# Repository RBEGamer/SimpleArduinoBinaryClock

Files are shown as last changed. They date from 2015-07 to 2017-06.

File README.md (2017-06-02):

# SimpleArduinoBinaryClock
Arduino based binary clock with hours and minutes display, nightmode and alarm.
It uses a Arsuino Nano and the WS2812 Leds,to show the time in a binary format.
The time, alarm time and nightmode time, can be set by the 4 switches on the back of the clock.
With the top button, you can change the color and stop the ringing alarm.
In my version of the clock, it comes with a 10x10x10cm  acryl plasic case.

# PARTS ELECTRONICS
* WS2813 led strip with 16 leds
* Any Arduino based board, but use a small one for a small case
* I2C RTC module (i use the DS3231 or you can use the DS1307)
* 5V Power supply or you power it with usb
* 5 Pushbuttons
* mini speaker
* 5 320 Ohm Pull-UP-Resistors

# TOOLS
* Solder equipment
* Knife
* Arcyl Glue
* Hotglue
* Wires
* Drill 6mm (depend on your button size)
* Dill 3mm (for the power cable-9

# PARTS CASE (10x10x10cm)
* 1 90x100x3mm LED PLATE
* 2 106x106x3mm at 75% transparency, FRONT PLATE
* 2 100x100x3mm LEDT/RIGHT PLATE
* 2 106x106x3mm TOP/BOTTOM PLATE

# SOFTWARE SETUP
* Download the sketch, lpcated on /CODE/beta_7_final.zip
* Download the latest Arduino IDE
* Download the Adafruit-Neopixel libary

# BUILD YOUR CLOCK
* Cut the ES2812 into 4 strips with 4 leds each
* Glue the 4 strips parallel to each other in the center of the LED PLATE
* Connect to the DI,VCC,GND pins of the right led strip 3x 5cm Wires (for the connection to the arduino)
* Now connect from right to left, DOUT to DI og the next left led strip
* at least connect to all strips, VCC and Gound
* Connect the VCC and Ground of the RTC Module to Arduino
* Connect the I2C pins to the Arduino. SCL(RTC) to A5 (SCL,ARDUINO) and SDA(RTC) to A4(SDA,Arduino)
* Connect VCC, Ground from the led strips to the Arduino
* Connect the DI of the led strips to D7 of the Arduino
* Connect on pin of the mini speaker to ground and the other to pin D13 of the Aduino
* Solder on each Button 3 Wires, on one pin two wires and on the other only one wire
* Connect the single wire of each button to Ground
* Solder of one of the two wires the pullup resistor and connect these to VCC(5V)
* Connect the last wire of each button to : D6 (sone alarm), D5(set alarm), D4 (set time), D2(add), D3(sub)

Now we are finih with the soldering, now we are building the case

* Drill to the BACK PLATE 4 holes for the switches: SET_ALARM, SET_TIME, ADD, SUB
* Drill a hole to the center of the TOP PLATE for the SONE switch
* Drill a second hole into the TOP PLATE for the speaker
* Drill a small hole into one of the bottom corners of the BACK PLATE for the power cable
* Place the switches at the right holes
* Glue the speaker next to the second hole of the TOP PLATE
* Glue the LED PLATE to the FRONT PLATE
* Glue the Arduino and the RTC Module to the back of the LED PLATE
* Assemble the other Plate around the bottom plate to get a cube

Now your clock is ready to use!!
Have FUN!

# SCHEMATIC AND PCB
I am currently working on a pcb for the clock. The KICAT file can be found at `src/bin_clock_kicad/`.

# IMAGES

Deatiled images of the build process, can be found at the /IMAGES folder

### FINAL CLOCK
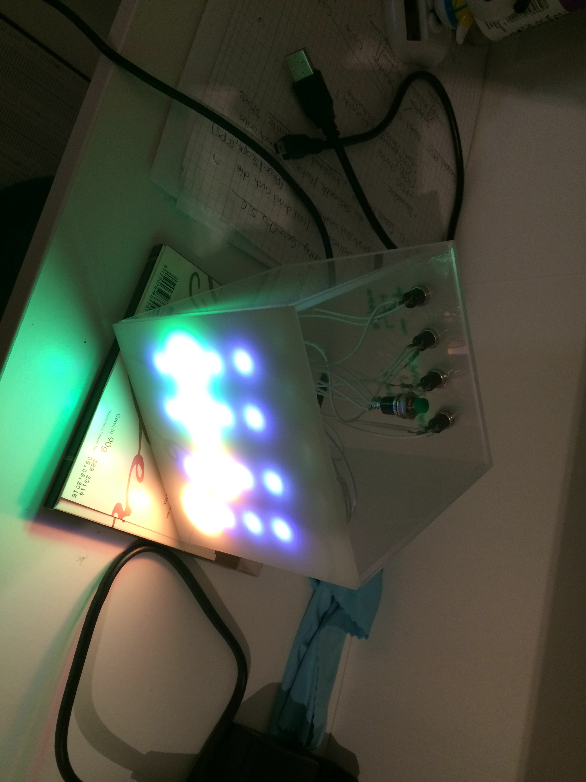
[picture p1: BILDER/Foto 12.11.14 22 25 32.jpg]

### Final hardware with connected buttons
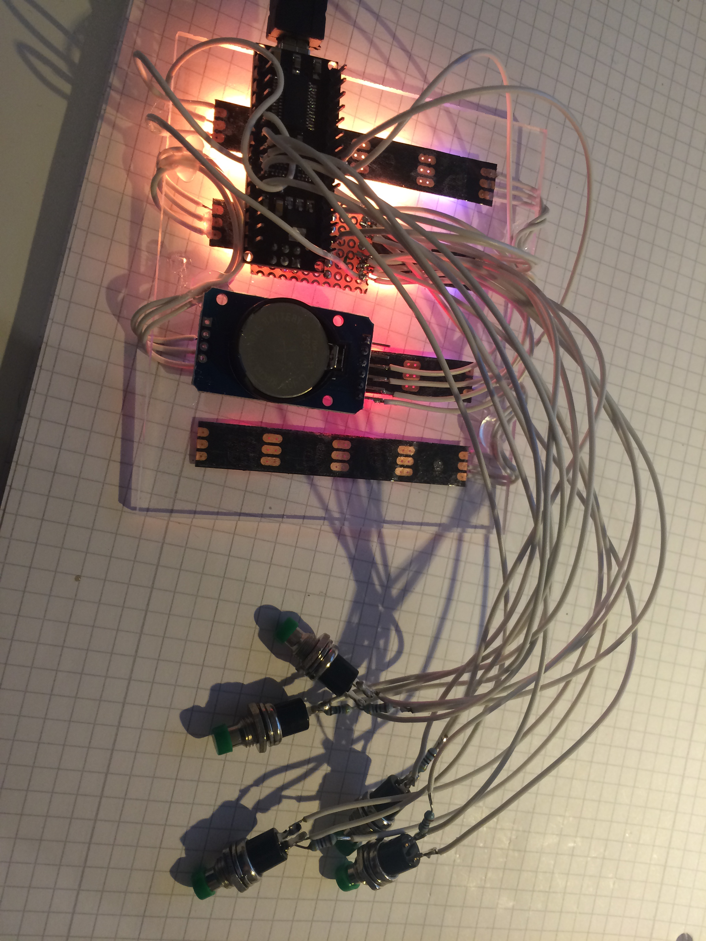
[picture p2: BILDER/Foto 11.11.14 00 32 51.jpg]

### placed WS2812 LED Strips
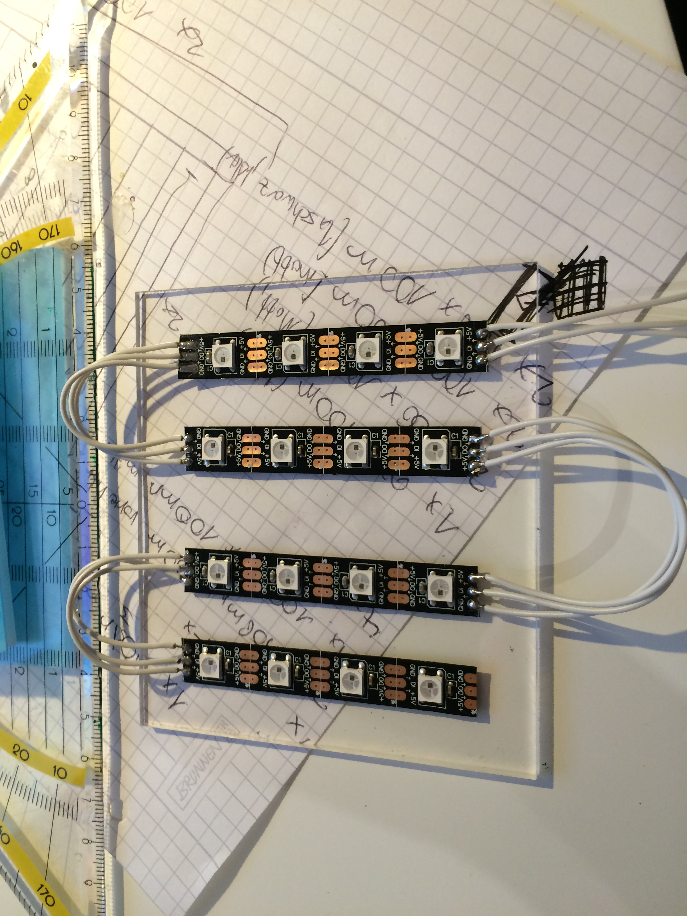
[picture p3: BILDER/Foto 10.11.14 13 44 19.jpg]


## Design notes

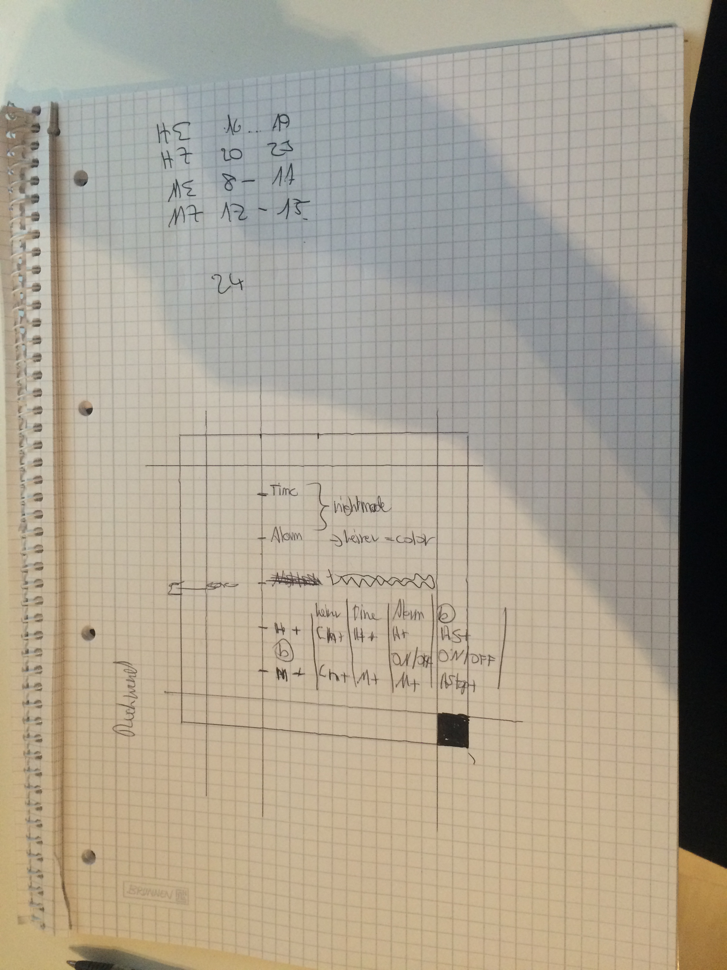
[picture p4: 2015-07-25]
BILDER/Foto 05.11.14 07 58 30.jpg

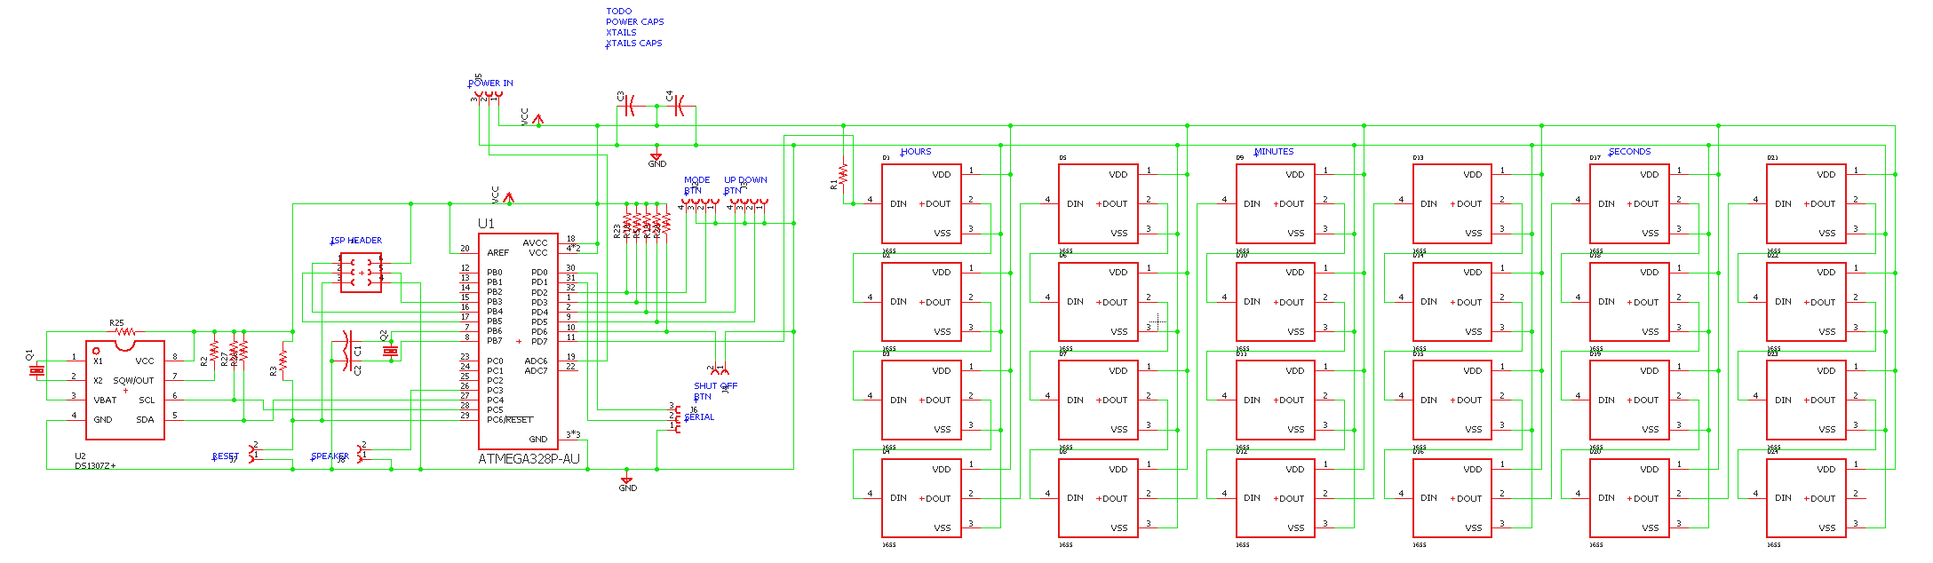
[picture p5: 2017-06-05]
BILDER/bin_clock_schem_fin.PNG

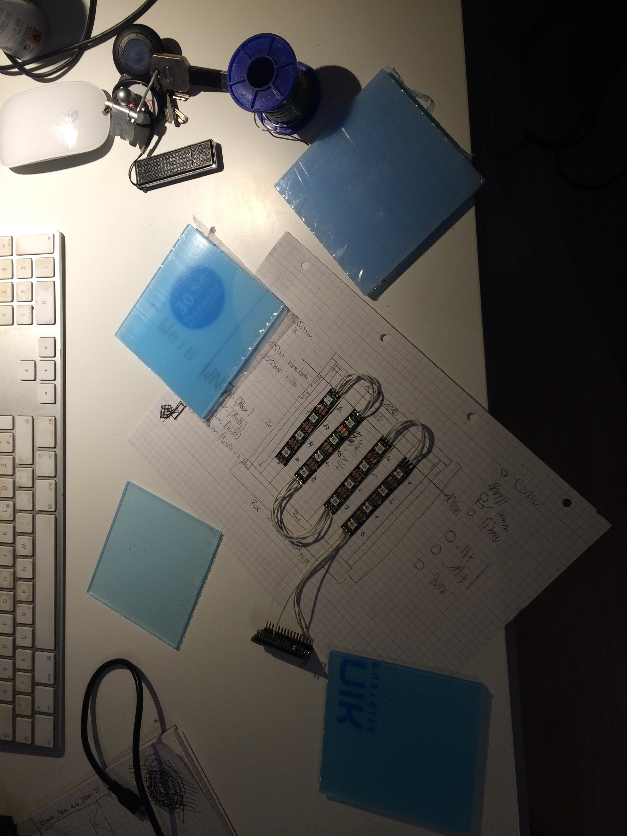
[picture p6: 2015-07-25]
BILDER/Foto 10.11.14 13 12 11.jpg

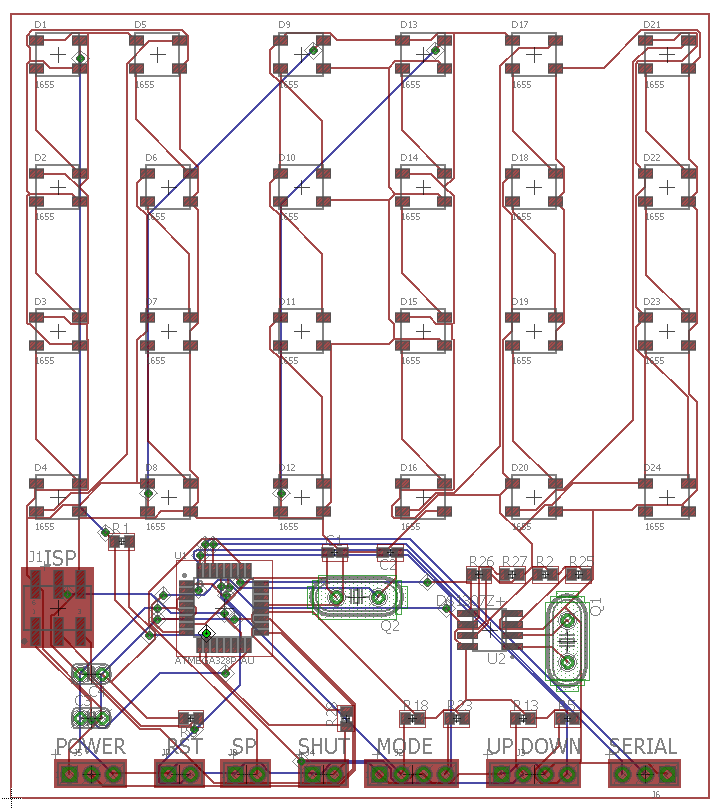
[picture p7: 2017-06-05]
BILDER/bin_clock_pcb_fin.PNG

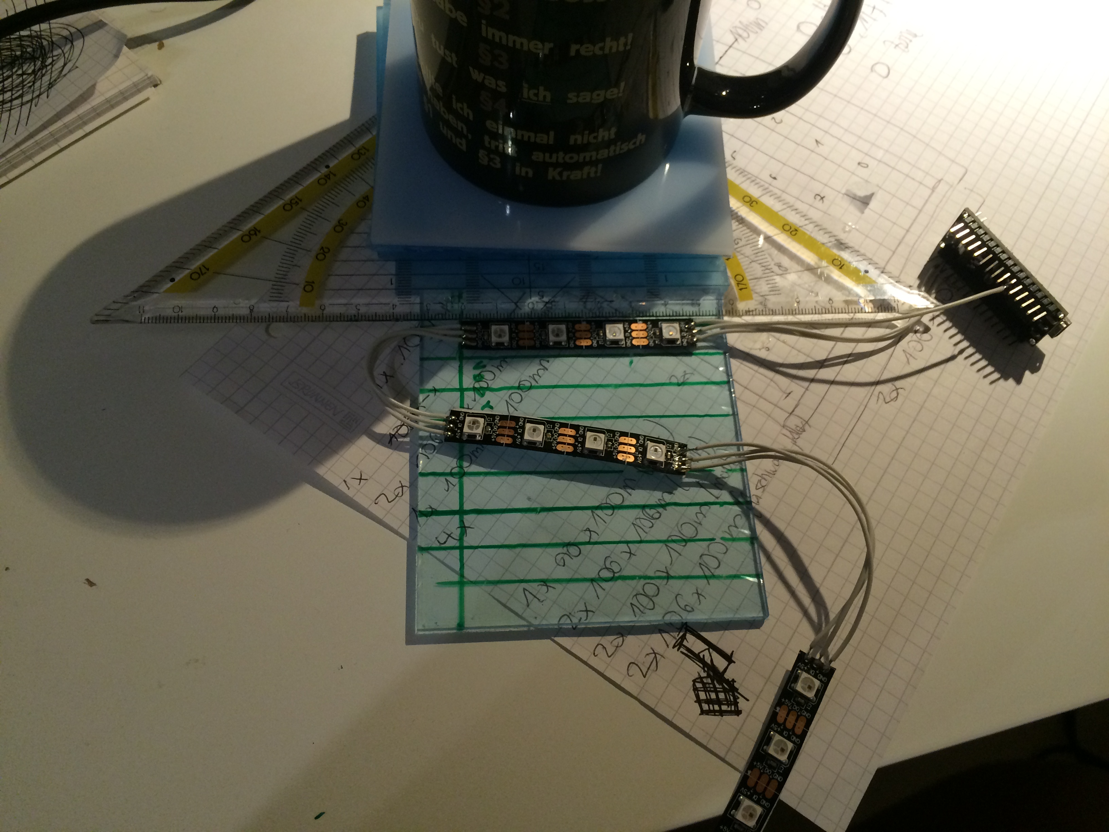
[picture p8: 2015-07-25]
BILDER/Foto 10.11.14 13 38 01.jpg

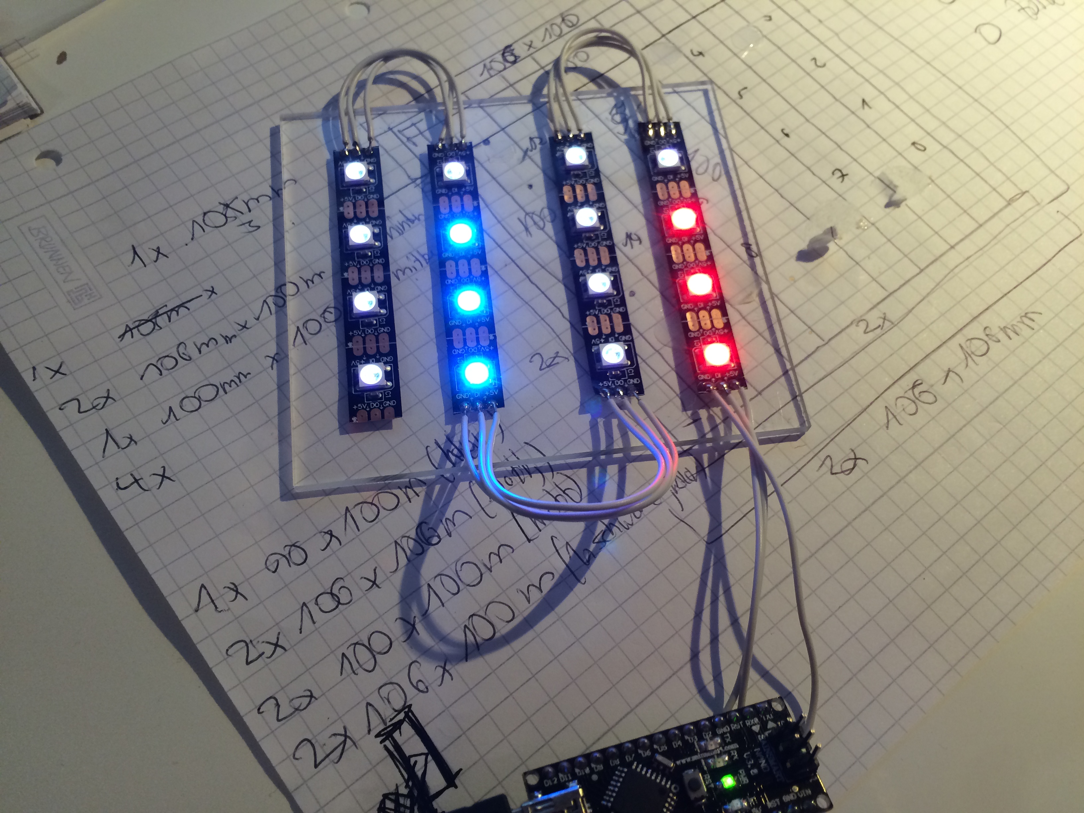
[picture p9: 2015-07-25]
BILDER/Foto 10.11.14 14 12 51.jpg

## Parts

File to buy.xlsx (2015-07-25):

Checklist
noch besorgen | Description | Amount
FALSE | 5 PushButtons green
FALSE | http://www.ebay.de/itm/350951233708?_trksid=p2059210.m2749.l2649&ssPageName=STRK%3AMEBIDX%3AIT | $9.85
FALSE | Arduino nano | $13.00
FALSE
TRUE | 1x 90x100m klar | $1.00
TRUE | 2x 106x106mm matt 75% | $1.00
TRUE | 2x 100x100 matt 75% | $1.00
TRUE | 2x 106x100m (1x schwarz, 1x klar) | $1.00
FALSE
FALSE
FALSE
FALSE
FALSE
FALSE
FALSE
FALSE
FALSE
FALSE
 | Total | $4.00

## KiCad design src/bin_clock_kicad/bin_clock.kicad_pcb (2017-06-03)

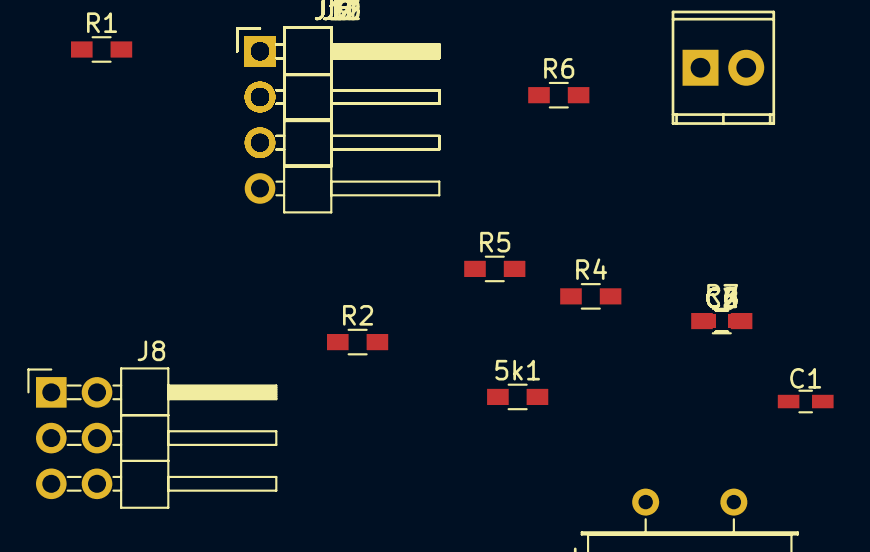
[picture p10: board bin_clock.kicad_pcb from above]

Board: 2 copper layers, 25 parts (0 on the bottom side), 11 nets, no tracks yet.

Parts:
5k1: R; R_0603_HandSoldering
C1, C2, C3, C4, C5, C6: C; C_0603_HandSoldering
J1: Screw_Terminal_1x02; TerminalBlock_Pheonix_MPT-2.54mm_2pol
J2: CONN_01X02; Pin_Header_Angled_1x01_Pitch2.54mm
J5: CONN_01X04; Pin_Header_Angled_1x04_Pitch2.54mm
J6, J7: CONN_01X03; Pin_Header_Angled_1x03_Pitch2.54mm
J8: CONN_02X03; Pin_Header_Angled_2x03_Pitch2.54mm
J9, J10, J11, J12, J13: CONN_01X02; Pin_Header_Angled_1x02_Pitch2.54mm
R1, R2, R4, R5, R6, R7: R; R_0603_HandSoldering
Y1: Crystal; Crystal_HC49-U_Horizontal

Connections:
+5V: 5k1.1, C1.1, C2.1, C5.1, C6.1, J1.1, J5.2, J7.1, J8.2, R1.1, R2.1, R4.1, R5.1, R6.1, R7.1
GND: C1.2, C2.2, C3.2, C4.2, C5.2, C6.2, J1.2, J2.1, J5.1, J6.2, J7.3, J8.6, J9.2, J10.2, J11.2, J12.2, J13.2
unnamed: 5k1.2, J13.1
unnamed: C3.1, Y1.1
unnamed: C4.1, Y1.2
unnamed: J7.2, R2.2
unnamed: J8.5, R1.2
unnamed: J9.1, R4.2
unnamed: J10.1, R5.2
unnamed: J11.1, R6.2
unnamed: J12.1, R7.2

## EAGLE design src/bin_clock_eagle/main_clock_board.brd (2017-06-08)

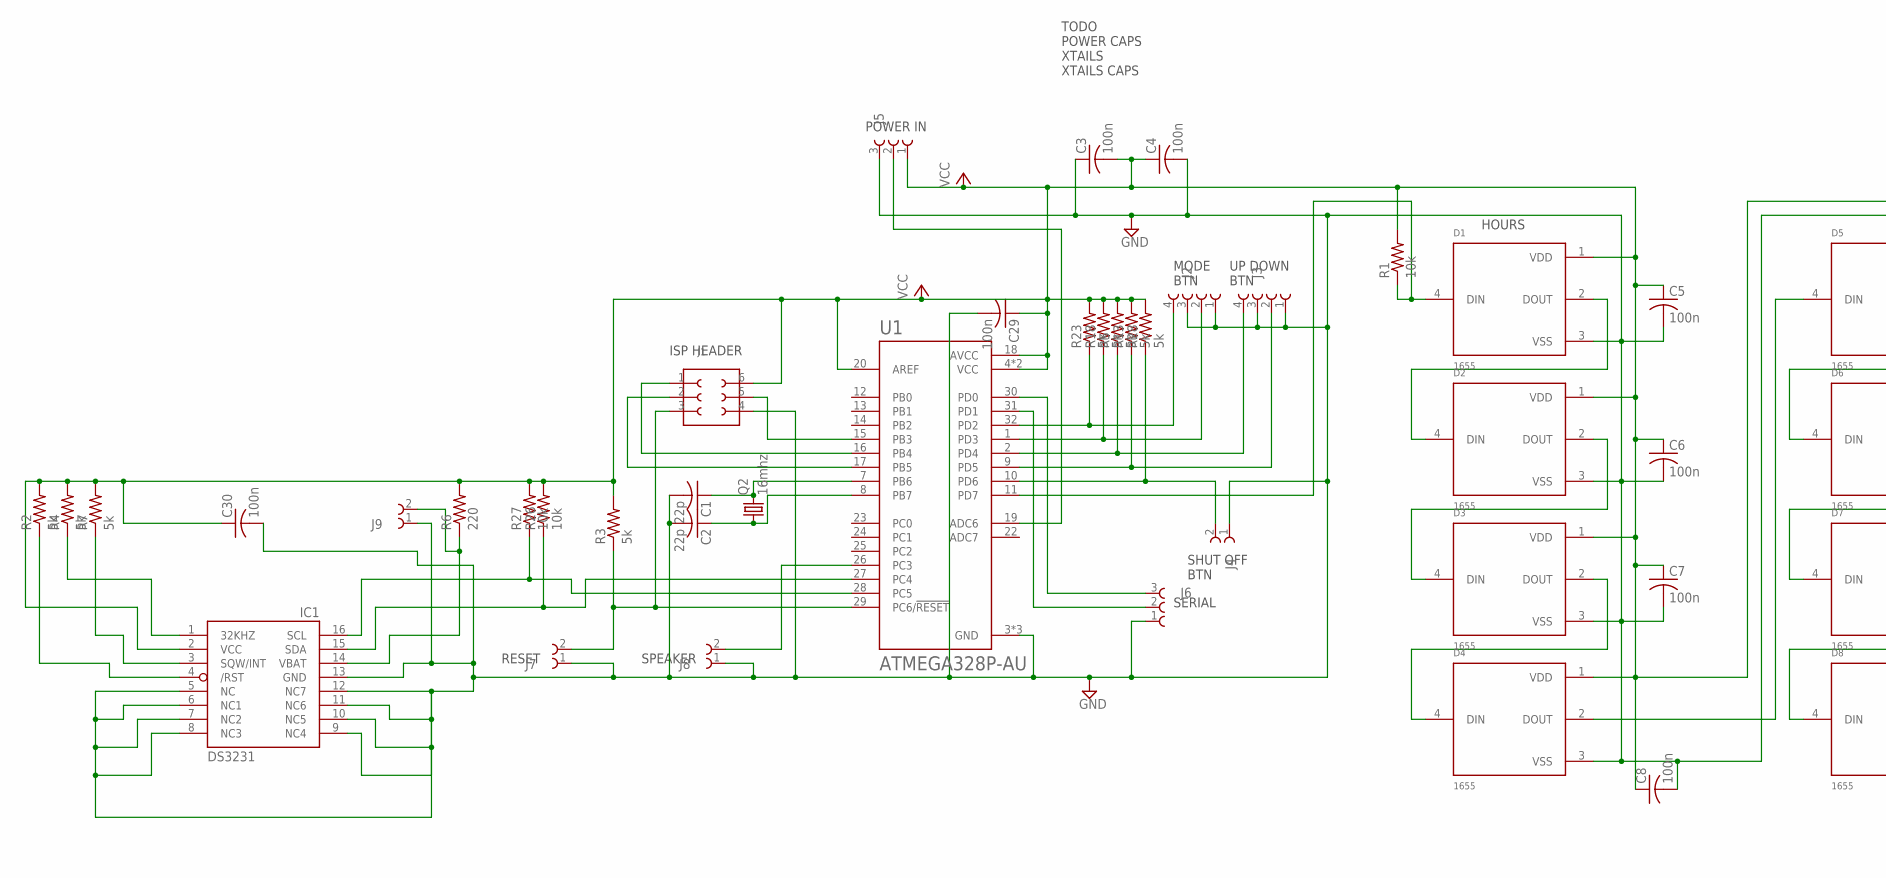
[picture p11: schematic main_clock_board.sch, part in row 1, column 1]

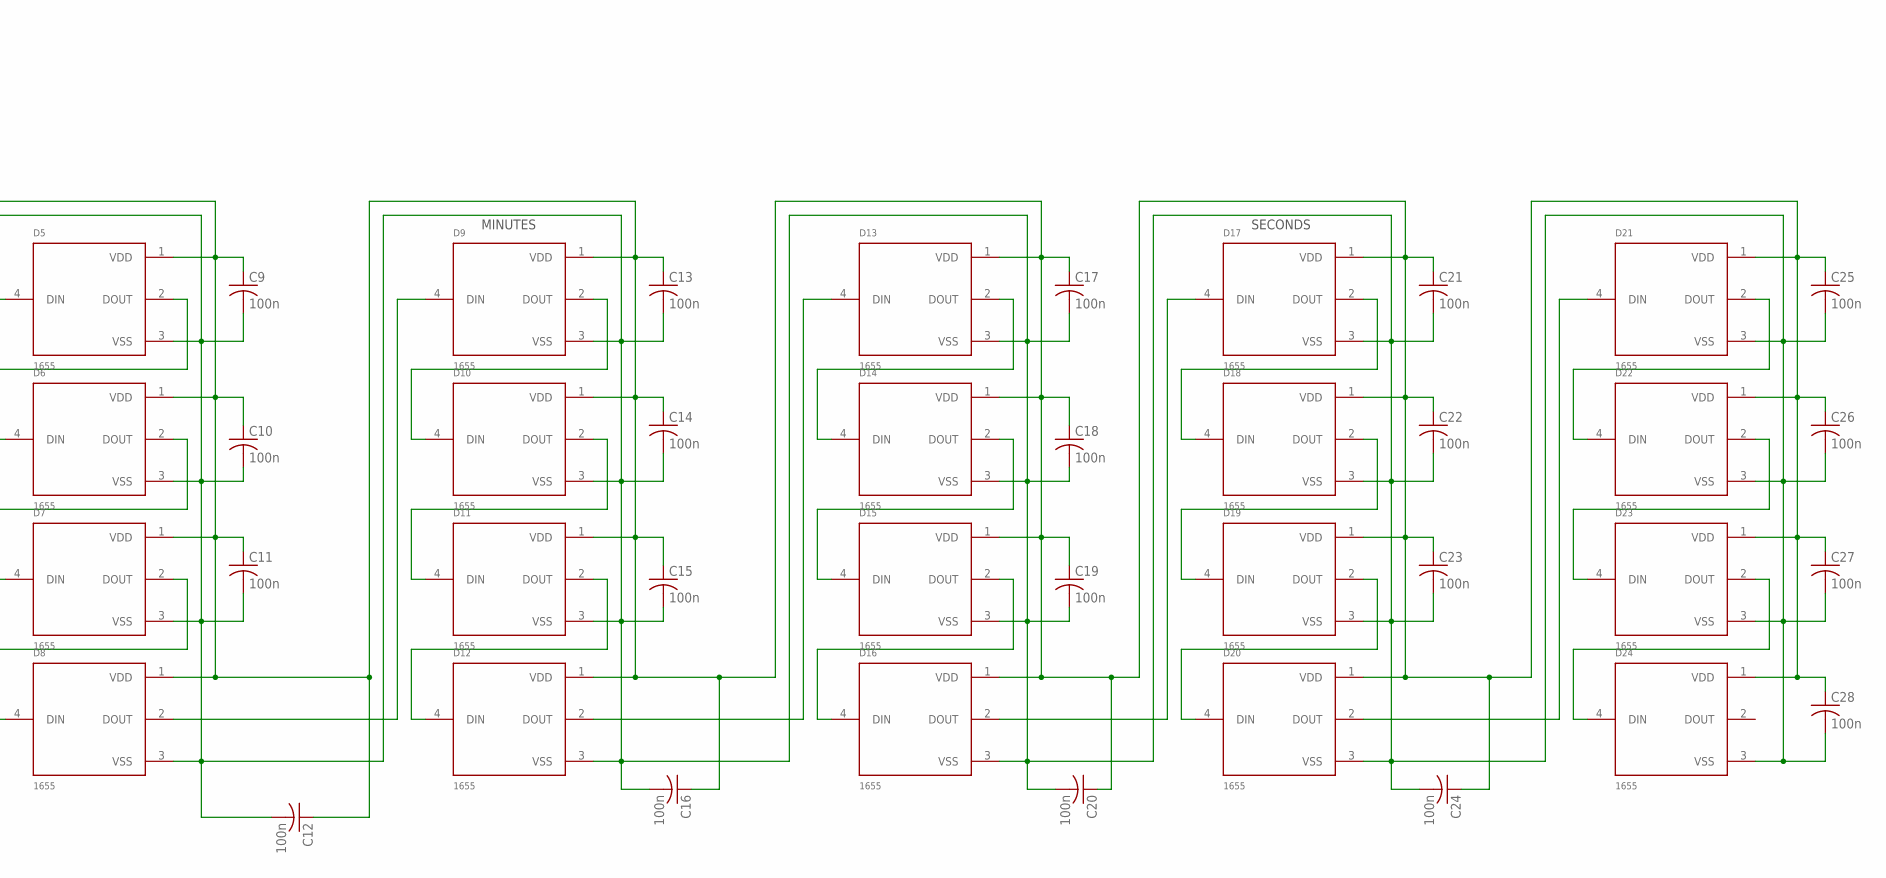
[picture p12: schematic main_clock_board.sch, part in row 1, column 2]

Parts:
C1, C2: 22p; C0603
C3, C4, C5, C6, C7, C8, C9, C10, C11, C12, C13, C14, C15, C16, C17, C18, C19, C20, C21, C22, C23, C24, C25, C26, C27, C28, C29, C30: 100n; C025-024X044
D1, D2, D3, D4, D5, D6, D7, D8, D9, D10, D11, D12, D13, D14, D15, D16, D17, D18, D19, D20, D21, D22, D23, D24: 1655; FCI_1655
IC1: DS3231/SO; SO16W
J1: 610X0621121
J2, J3: 61300411121
J4, J7, J8, J9: 61300211121
J5, J6: 61300311121
Q2: 16mhz; HC49/S
R1, R26, R27: 10k; R0603
R2, R3, R4, R5, R7, R13, R18, R23, R28: 5k; R0603
R6: 220; R0603
U1: ATMEGA328P-AU; QFP80P900X900X120-32N

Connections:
GND: C1.2, C2.2, C3.1, C4.2, C5.2, C6.2, C7.2, C8.2, C9.2, C10.2, C11.2, C12.2, C13.2, C14.2, C15.2, C16.2, C17.2, C18.2, C19.2, C20.2, C21.2, C22.2, C23.2, C24.2, C25.2, C26.2, C27.2, C28.2, C29.2, C30.2, D1.3 (VSS), D2.3 (VSS), D3.3 (VSS), D4.3 (VSS), D5.3 (VSS), D6.3 (VSS), D7.3 (VSS), D8.3 (VSS), D9.3 (VSS), D10.3 (VSS), D11.3 (VSS), D12.3 (VSS), D13.3 (VSS), D14.3 (VSS), D15.3 (VSS), D16.3 (VSS), D17.3 (VSS), D18.3 (VSS), D19.3 (VSS), D20.3 (VSS), D21.3 (VSS), D22.3 (VSS), D23.3 (VSS), D24.3 (VSS), IC1.5 (NC), IC1.6 (NC1), IC1.7 (NC2), IC1.8 (NC3), IC1.9 (NC4), IC1.10 (NC5), IC1.11 (NC6), IC1.12 (NC7), IC1.13 (GND), J1.4, J2.1 (4), J2.3 (2), J3.1 (4), J3.3 (2), J4.1, J5.3 (1), J6.1 (3), J7.1, J8.1, J9.1, U1.3 (GND), U1.5 (GND), U1.21 (GND)
unnamed: D1.2 (DOUT), D2.4 (DIN)
unnamed: IC1.15 (SDA), R26.1, U1.27 (PC4)
unnamed: D2.2 (DOUT), D3.4 (DIN)
unnamed: D3.2 (DOUT), D4.4 (DIN)
unnamed: D4.2 (DOUT), D5.4 (DIN)
unnamed: D5.2 (DOUT), D6.4 (DIN)
unnamed: D6.2 (DOUT), D7.4 (DIN)
unnamed: D7.2 (DOUT), D8.4 (DIN)
unnamed: IC1.16 (SCL), R27.1, U1.28 (PC5)
unnamed: J1.3, J7.2, R3.1, U1.29 (PC6/!RESET)
unnamed: D8.2 (DOUT), D9.4 (DIN)
unnamed: D9.2 (DOUT), D10.4 (DIN)
unnamed: J1.1, U1.16 (PB4)
unnamed: IC1.4 (/RST), R2.1
unnamed: D10.2 (DOUT), D11.4 (DIN)
unnamed: D11.2 (DOUT), D12.4 (DIN)
unnamed: D12.2 (DOUT), D13.4 (DIN)
unnamed: D13.2 (DOUT), D14.4 (DIN)
unnamed: D14.2 (DOUT), D15.4 (DIN)
unnamed: D15.2 (DOUT), D16.4 (DIN)
unnamed: J2.4 (1), R23.1, U1.32 (PD2)
unnamed: D16.2 (DOUT), D17.4 (DIN)
unnamed: D17.2 (DOUT), D18.4 (DIN)
unnamed: J1.2, U1.17 (PB5)
unnamed: J2.2 (3), R18.1, U1.1 (PD3)
unnamed: D18.2 (DOUT), D19.4 (DIN)
unnamed: D19.2 (DOUT), D20.4 (DIN)
unnamed: D20.2 (DOUT), D21.4 (DIN)
unnamed: D21.2 (DOUT), D22.4 (DIN)
unnamed: D22.2 (DOUT), D23.4 (DIN)
unnamed: D23.2 (DOUT), D24.4 (DIN)
unnamed: J3.4 (1), R5.1, U1.2 (PD4)
unnamed: J3.2 (3), R13.1, U1.9 (PD5)
unnamed: D1.4 (DIN), R1.1, U1.11 (PD7)
unnamed: J4.2, R28.1, U1.10 (PD6)
unnamed: J1.5, U1.15 (PB3)
unnamed: J6.2, U1.31 (PD1)
unnamed: J6.3 (1), U1.30 (PD0)
unnamed: J5.2, U1.19 (ADC6)
unnamed: J8.2, U1.26 (PC3)
unnamed: IC1.1 (32KHZ), R4.1
unnamed: IC1.14 (VBAT), J9.2, R6.1
unnamed: IC1.3 (SQW/INT), R7.1
unnamed: C1.1, Q2.2, U1.7 (PB6)
unnamed: C2.1, Q2.1, U1.8 (PB7)
VCC: C3.2, C4.1, C5.1, C6.1, C7.1, C8.1, C9.1, C10.1, C11.1, C12.1, C13.1, C14.1, C15.1, C16.1, C17.1, C18.1, C19.1, C20.1, C21.1, C22.1, C23.1, C24.1, C25.1, C26.1, C27.1, C28.1, C29.1, C30.1, D1.1 (VDD), D2.1 (VDD), D3.1 (VDD), D4.1 (VDD), D5.1 (VDD), D6.1 (VDD), D7.1 (VDD), D8.1 (VDD), D9.1 (VDD), D10.1 (VDD), D11.1 (VDD), D12.1 (VDD), D13.1 (VDD), D14.1 (VDD), D15.1 (VDD), D16.1 (VDD), D17.1 (VDD), D18.1 (VDD), D19.1 (VDD), D20.1 (VDD), D21.1 (VDD), D22.1 (VDD), D23.1 (VDD), D24.1 (VDD), IC1.2 (VCC), J1.6, J5.1 (3), R1.2, R2.2, R3.2, R4.2, R5.2, R6.2, R7.2, R13.2, R18.2, R23.2, R26.2, R27.2, R28.2, U1.4 (VCC), U1.6 (VCC), U1.18 (AVCC), U1.20 (AREF)

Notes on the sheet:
ISP HEADER
MODE BTN
UP DOWN BTN
SHUT OFF BTN
HOURS
MINUTES
SECONDS
SERIAL
RESET
SPEAKER
TODO POWER CAPS XTAILS XTAILS CAPS
POWER IN

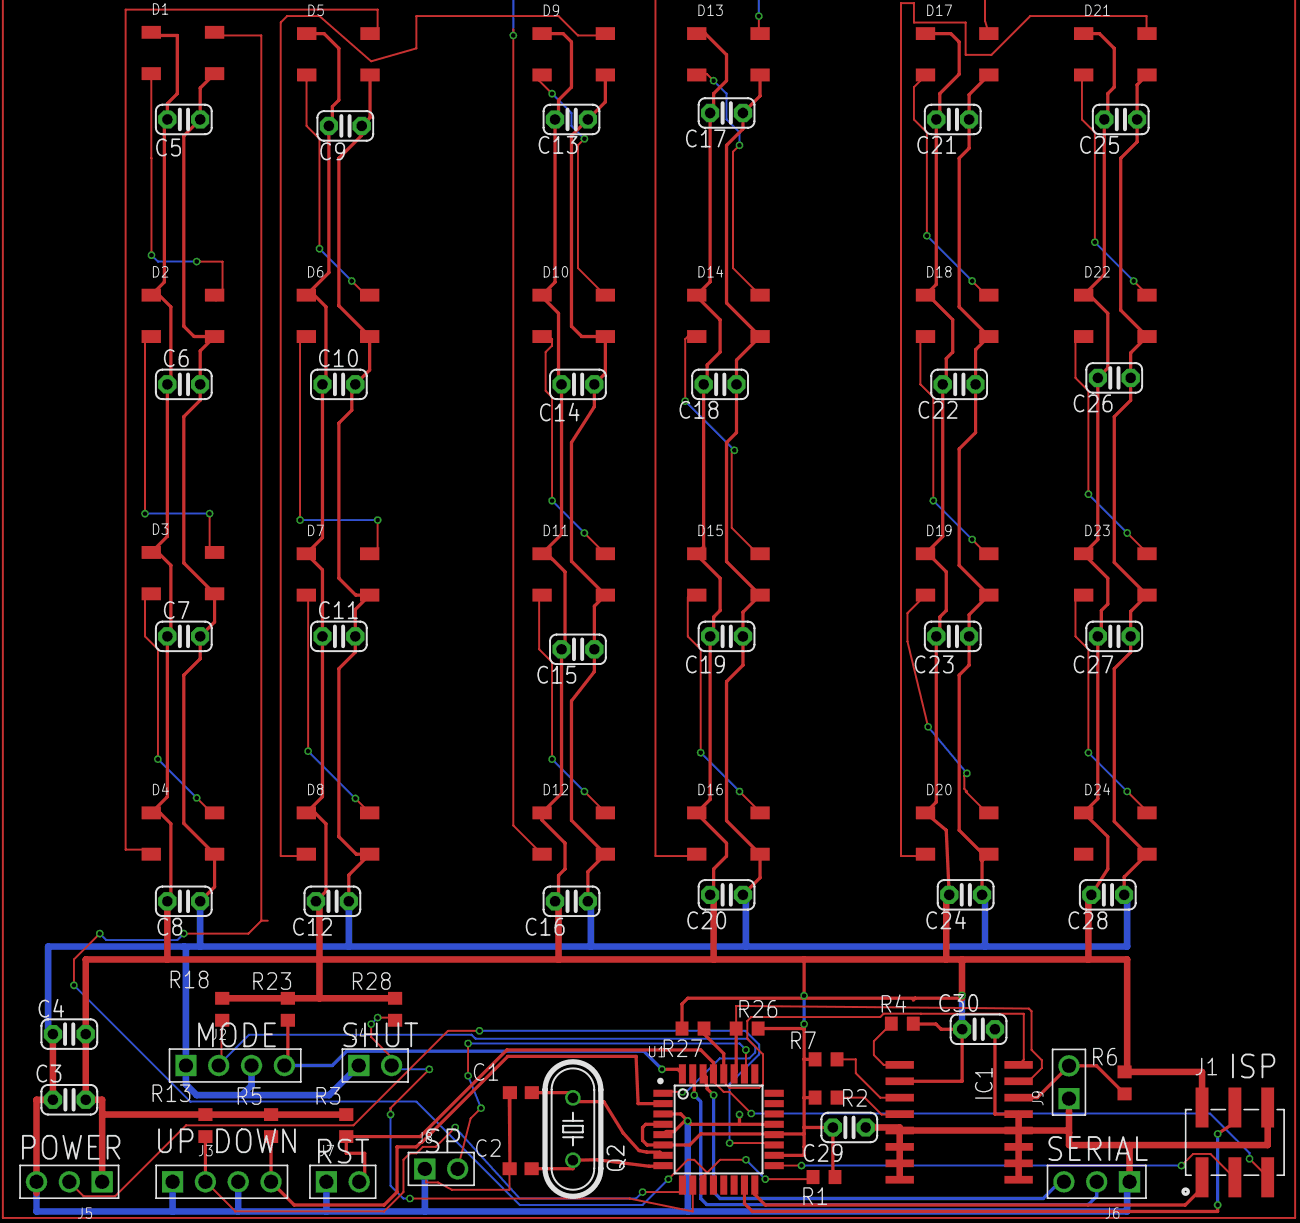
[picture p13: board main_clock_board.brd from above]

Board: 2 copper layers, 79 parts (0 on the bottom side), 47 nets.

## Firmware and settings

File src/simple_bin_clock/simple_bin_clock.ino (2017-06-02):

//5 BUTTONS



#include "Wire.h" //damit man i2c benutzen kann
#include <EEPROM.h>
#include <Adafruit_NeoPixel.h> //damit man die led benutzen kann
const int btn_add_pin = 2;
const int btn_sub_pin = 3;
const int btn_time_pin = 4;
const int btn_alarm_pin = 5;
const int btn_sone_pin = 6;
const int led_pin = 7; //an welchem pin ist der Din vom strip angeschlossen
const int led_amount = 16; //anzahl der leds im strip (2x4*2)
const int beeper_pin = 13; //pin fuer den beeper
//hier sind die states der buttons drinne 1 wenn gedrckt 0 wenn nicht
int btn_add_state = 0;
int btn_sub_state = 0;
int btn_time_state = 0;
int btn_alarm_state = 0;
int btn_sone_state = 0;
int prev_state_button = 0;
//fuer das farbrad
byte wheel_pos_h = 0; //0-255 Farbe der stunden
byte wheel_pos_m = 0;//0-255 Farbe der minuten
//hier werden die farben fuer minuten und stunden gespeichert  0=R, 1=G, 2=B
int wheel_color_h[3]; 
int wheel_color_m[3];
//hier ist die aus farbe (r,g,b)
int wheel_color_h_aus[3] = {1,1,1};
int wheel_color_m_aus[3] = {1,1,1};
//hier ist die nachtmode farbe (r,g,b)
int nightmode_color_m[3] = {0,0,0};
int nightmode_color_h[3] = {0,0,0};

int nightmode_color_m_aus[3] = {0,0,0};
int nightmode_color_h_aus[3] = {0,0,0};
//NACHTMODE VARS
int nthstate = 0; // ist der nachtmode gerade aktiv (0-1)
int nthen = 0; // nachmode an oder aus (0-1)
int nth = 0; //startstunde des nachtmode (0-23)
int nthe = 7;//endstunde des nachtmode)0-23)
//ALARM VARS
int alarm_en = 0; //ALARM ON/OFF (0-1)
int alarm_h = 0; //Alarm-Stunde
int alarm_m = 0; // Alarm-Minute
int alarm_process = 0;  //klingelt es gerade
int alarm_state = 0; // klingel trigger
//damit werden die leds angesprochen dadurch ist das ganze sehr einfach
Adafruit_NeoPixel strip = Adafruit_NeoPixel(led_amount, led_pin, NEO_RGB + NEO_KHZ800);
//damit man das uhrmodul lesen kann denn die hat eine bestimmte adresse und die ist hier definiert
#define DS1307_I2C_ADDRESS 0x68  // This is the I2C address
// Arduino version compatibility Pre-Compiler Directives
#if defined(ARDUINO) && ARDUINO >= 100   // Arduino v1.0 and newer
  #define I2C_WRITE Wire.write 
  #define I2C_READ Wire.read
#else                                   // Arduino Prior to v1.0 
  #define I2C_WRITE Wire.send 
  #define I2C_READ Wire.receive
#endif
byte decToBcd(byte val){return ( (val/10*16) + (val%10) );}
byte bcdToDec(byte val){return ( (val/16*10) + (val%16) );}
//HIER SIND ALLE ZEIT VARIABLEN DRINNEN
byte second, minute, hour, dayOfWeek, dayOfMonth, month, year, _hour;
byte test;
byte zero;
//variablen fur das splitten von decimaler zeit zu binaer
int _value;
byte binwert_s_z;
byte binwert_s_e;
int s_z = 0;
int s_e = 0; 



void setup() {
  // put your setup code here, to run once:
  Wire.begin();
  Serial.begin(115200);
  zero=0x00;
  strip.begin();
  strip.show(); // Initialize all pixels to 'off'

eeprom_read();




/*
   second = 0;
   minute = 29;
   hour = 20;

   dayOfWeek = 1;
   dayOfMonth = 1;
   month = 1;
   year= 1;
   Wire.beginTransmission(DS1307_I2C_ADDRESS);
   I2C_WRITE(zero);
   I2C_WRITE(decToBcd(second) & 0x7f);    // 0 to bit 7 starts the clock
   I2C_WRITE(decToBcd(minute));
   I2C_WRITE(decToBcd(hour));      // If you want 12 hour am/pm you need to set                                  // bit 6 (also need to change readDateDs1307)
   I2C_WRITE(decToBcd(dayOfWeek));
   I2C_WRITE(decToBcd(dayOfMonth));
   I2C_WRITE(decToBcd(month));
   I2C_WRITE(decToBcd(year));
   Wire.endTransmission(); 
*/   
   
   
}



void loop() {
  // put your main code here, to run repeatedly:
color_wheel();
getDateDs1307();
button();
soundAlarm();
delay(200);
//display_time(7, 7);  
}


void color_wheel(){
wheel_h();
wheel_m();
}






// Gets the date and time from the ds1307 and prints result
void getDateDs1307()
{
  // Reset the register pointer
  Wire.beginTransmission(DS1307_I2C_ADDRESS);
  I2C_WRITE(zero);
  Wire.endTransmission();
  Wire.requestFrom(DS1307_I2C_ADDRESS, 7);
  second     = bcdToDec(I2C_READ() & 0x7f);
  minute     = bcdToDec(I2C_READ());
  hour       = bcdToDec(I2C_READ() & 0x3f);  // Need to change this if 12 hour am/pm
  dayOfWeek  = bcdToDec(I2C_READ());
  dayOfMonth = bcdToDec(I2C_READ());
  month      = bcdToDec(I2C_READ());
  year       = bcdToDec(I2C_READ());

if(nthen == 1){
//LIEGT DIE ZEIT ZWISCHEN DEN BEIDEN GERENDZEN
if(nth > nthe-1){
//WENN ANFANG > ALS ENDE
if(hour <= nth && hour <= nthe-1){
nthstate = 1;
}else if(hour >= nth && hour >= nthe-1){
nthstate = 1;
}else{
nthstate = 0;
}
}else if (nth < nthe-1){
  //WENN ANFANG > ALS ENDE
if(hour <= nth && hour >= nthe-1){
nthstate = 1;
}else if(hour >= nth && hour <= nthe-1){
nthstate = 1;
}else{
nthstate = 0;
}
}else if( nth == nthe-1){
  if(hour == nth || hour == nthe-1){
  nthstate = 1;
  }else{
  nthstate = 0;
  }
}else{
nthstate = 0;
}
}else{
nthstate == 0;
}
if(nthstate == 1 && nthen == 1){

//NACHTMODE AKTIVE

//Hier einfach die farben mit der nachtmode farbe berschreoben
 wheel_color_h[0] = nightmode_color_h[0]; 
 wheel_color_h[1] = nightmode_color_h[1]; 
 wheel_color_h[2] = nightmode_color_h[2]; 

wheel_color_m[0] = nightmode_color_m[0];
wheel_color_m[1] = nightmode_color_m[1];
wheel_color_m[2] = nightmode_color_m[2];


wheel_color_h_aus[0] = nightmode_color_h_aus[0];
wheel_color_h_aus[1] = nightmode_color_h_aus[1];
wheel_color_h_aus[2] = nightmode_color_h_aus[2];

wheel_color_m_aus[0] = nightmode_color_m_aus[0];
wheel_color_m_aus[1] = nightmode_color_m_aus[1];
wheel_color_m_aus[2] = nightmode_color_m_aus[2];


}else{
  
  //NACHTMODE NICHT AKTIV


  
}
display_time(hour, minute);  
}





void setDateDs1307()                
{
   second = 0;
  // minute = 0;
  // hour = 0;

   dayOfWeek = 1;
   dayOfMonth = 1;
   month = 1;
   year= 1;
   Wire.beginTransmission(DS1307_I2C_ADDRESS);
   I2C_WRITE(zero);
   I2C_WRITE(decToBcd(second) & 0x7f);    // 0 to bit 7 starts the clock
   I2C_WRITE(decToBcd(minute));
   I2C_WRITE(decToBcd(hour));      // If you want 12 hour am/pm you need to set                                  // bit 6 (also need to change readDateDs1307)
   I2C_WRITE(decToBcd(dayOfWeek));
   I2C_WRITE(decToBcd(dayOfMonth));
   I2C_WRITE(decToBcd(month));
   I2C_WRITE(decToBcd(year));
   Wire.endTransmission(); 
}







 void display_time(int _hour, int _minute){   
   if(_minute > 59){_minute-=59;}
_value = _minute;
 s_z = (_value % 100) / 10;
 s_e = _value % 10;
 binwert_s_z = byte(s_z);
 binwert_s_e = byte(s_e);
      //MINUTEN ZEHNER
   if(bitRead(binwert_s_z,0) == 1){
    strip.setPixelColor(7,  strip.Color(wheel_color_m[0], wheel_color_m[1], wheel_color_m[2])); 
   }else{
      strip.setPixelColor(7,  strip.Color(wheel_color_m_aus[0], wheel_color_m_aus[1], wheel_color_m_aus[2])); 
   }  
   if(bitRead(binwert_s_z,1) == 1){
 strip.setPixelColor(6,  strip.Color(wheel_color_m[0], wheel_color_m[1], wheel_color_m[2])); 
   }else{
    strip.setPixelColor(6,  strip.Color(wheel_color_m_aus[0], wheel_color_m_aus[1], wheel_color_m_aus[2])); 
   } 
   if(bitRead(binwert_s_z,2) == 1){
     strip.setPixelColor(5,  strip.Color(wheel_color_m[0], wheel_color_m[1], wheel_color_m[2])); 
   }else{
     strip.setPixelColor(5,  strip.Color(wheel_color_m_aus[0], wheel_color_m_aus[1], wheel_color_m_aus[2])); 
   }  
   if(bitRead(binwert_s_z,3) == 1){
     strip.setPixelColor(4,  strip.Color(wheel_color_m[0], wheel_color_m[1], wheel_color_m[2])); 
   }else{
strip.setPixelColor(4,  strip.Color(wheel_color_m_aus[0], wheel_color_m_aus[1], wheel_color_m_aus[2])); 
   }  
   //MINUTE EINER
   if(bitRead(binwert_s_e,0) == 1){
   strip.setPixelColor(0,  strip.Color(wheel_color_m[0], wheel_color_m[1], wheel_color_m[2])); 
   }else{
strip.setPixelColor(0,  strip.Color(wheel_color_m_aus[0], wheel_color_m_aus[1], wheel_color_m_aus[2])); 
   }  
   if(bitRead(binwert_s_e,1) == 1){
    strip.setPixelColor(1,  strip.Color(wheel_color_m[0], wheel_color_m[1], wheel_color_m[2])); 
   }else{
     strip.setPixelColor(1,  strip.Color(wheel_color_m_aus[0], wheel_color_m_aus[1], wheel_color_m_aus[2])); 
   } 
   if(bitRead(binwert_s_e,2) == 1){
 strip.setPixelColor(2,  strip.Color(wheel_color_m[0], wheel_color_m[1], wheel_color_m[2])); 
   }else{
  strip.setPixelColor(2,  strip.Color(wheel_color_m_aus[0], wheel_color_m_aus[1], wheel_color_m_aus[2])); 
   }  
   if(bitRead(binwert_s_e,3) == 1){
   strip.setPixelColor(3,  strip.Color(wheel_color_m[0], wheel_color_m[1], wheel_color_m[2])); 
   }else{
    strip.setPixelColor(3,  strip.Color(wheel_color_m_aus[0], wheel_color_m_aus[1], wheel_color_m_aus[2])); 
   }
     if(_hour > 23){_hour-=24;}
_value = _hour;
 s_z = (_value % 100) / 10;
 s_e = _value % 10;
 binwert_s_z = byte(s_z);
 binwert_s_e = byte(s_e);
 
      //HOUR ZEHNER
   if(bitRead(binwert_s_z,3) == 1){
  strip.setPixelColor(12,  strip.Color(wheel_color_h[0], wheel_color_h[1], wheel_color_h[2])); 
   }else{
     strip.setPixelColor(12,  strip.Color(wheel_color_h_aus[0], wheel_color_h_aus[1], wheel_color_h_aus[2]));
   }  
   if(bitRead(binwert_s_z,2) == 1){
  strip.setPixelColor(13,  strip.Color(wheel_color_h[0], wheel_color_h[1], wheel_color_h[2])); 
   }else{
       strip.setPixelColor(13,  strip.Color(wheel_color_h_aus[0], wheel_color_h_aus[1], wheel_color_h_aus[2]));
   } 
   if(bitRead(binwert_s_z,1) == 1){
   strip.setPixelColor(14,  strip.Color(wheel_color_h[0], wheel_color_h[1], wheel_color_h[2])); ;
   }else{
       strip.setPixelColor(14,  strip.Color(wheel_color_h_aus[0], wheel_color_h_aus[1], wheel_color_h_aus[2]));
   }  
   if(bitRead(binwert_s_z,0) == 1){
   strip.setPixelColor(15,  strip.Color(wheel_color_h[0], wheel_color_h[1], wheel_color_h[2])); 
   }else{
     strip.setPixelColor(15,  strip.Color(wheel_color_h_aus[0], wheel_color_h_aus[1], wheel_color_h_aus[2]));
   }
   //HOUR EINER
   if(bitRead(binwert_s_e,3) == 1){
 strip.setPixelColor(11,  strip.Color(wheel_color_h[0], wheel_color_h[1], wheel_color_h[2])); 
   }else{
     strip.setPixelColor(11,  strip.Color(wheel_color_h_aus[0], wheel_color_h_aus[1], wheel_color_h_aus[2]));
   }  
   if(bitRead(binwert_s_e,2) == 1){
   strip.setPixelColor(10,  strip.Color(wheel_color_h[0], wheel_color_h[1], wheel_color_h[2])); 
   }else{
      strip.setPixelColor(10,  strip.Color(wheel_color_h_aus[0], wheel_color_h_aus[1], wheel_color_h_aus[2]));
   } 
   if(bitRead(binwert_s_e,1) == 1){
  strip.setPixelColor(9,  strip.Color(wheel_color_h[0], wheel_color_h[1], wheel_color_h[2])); 
   }else{
      strip.setPixelColor(9,  strip.Color(wheel_color_h_aus[0], wheel_color_h_aus[1], wheel_color_h_aus[2]));
   }  
   if(bitRead(binwert_s_e,0) == 1){
   strip.setPixelColor(8,  strip.Color(wheel_color_h[0], wheel_color_h[1], wheel_color_h[2])); 
   }else{
       strip.setPixelColor(8,  strip.Color(wheel_color_h_aus[0], wheel_color_h_aus[1], wheel_color_h_aus[2]));
   }
    Serial.println("Time : " + String(hour) + ":" + String(minute) + ":" + String(second));
 strip.show();
 }

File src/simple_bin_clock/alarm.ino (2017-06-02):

void stop_alarm(){
    if(alarm_state == 1 && alarm_en ==1){
    alarm_state = 0;
    alarm_state =0;
  while(minute == alarm_m){ //SOLANGE warten bis die zeit vorbei ist
 
  Serial.println("ALARM DELAY WHILE"); 
  getDateDs1307();
  
  
  }
 
 alarm_process = 0; 
  alarm_state = 0; 
  delay(2000);
  
  
    }
}


void soundAlarm() {
  
  if(hour == alarm_h && minute == alarm_m && alarm_en == 1 && alarm_process == 0 ){
    alarm_process = 1;
    alarm_state = 1;
    
    
  }else{
 
  }
  

  
  if(alarm_state == 1 && alarm_en ==1){
    
    
    
    
 float alarmFrequency=1400; // The value for the alarm tone in Hz
 float period = (1.0 / alarmFrequency) * 1000000;
 long beepDuration=250000; // the time in microseconds (0.25 seconds)
 long elapsedTime = 0;
 while (elapsedTime < beepDuration) {
 digitalWrite(beeper_pin,HIGH);
 delayMicroseconds(period / 2);
 digitalWrite(beeper_pin, LOW);
 delayMicroseconds(period / 2);
 elapsedTime += (period);
 }
 digitalWrite(beeper_pin, LOW); 
 delayMicroseconds(beepDuration);
 }
  
}

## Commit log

2017-06-02 added kicad files
    [bin_clock.kicad_pcb, bin_clock.sch]
2017-06-03 added missing sone button
    [bin_clock.sch]
2017-06-03 added all leds
    [bin_clock.sch]
2017-06-03 added fist pcb board
    [_saved_bin_clock.sch, bin_clock.dsn, bin_clock.kicad_pcb]
2017-06-03 pcb rework needed
    [_saved_bin_clock.sch, bin_clock.kicad_pcb, bin_clock.sch]
2017-06-03 added final schematic in eagle
    please use the egale project first.
    feel free to complete the kicad
    [main_clock_board.brd, main_clock_board.sch]
2017-06-04 added vcc gnd pins
    [main_clock_board.brd]
2017-06-05 added part values
    [DRILEGEND.CFG, main_clock_board.sch]
2017-06-05 pcb size rework
    [DRILEGEND.CFG, main_clock_board.brd, main_clock_board.sch]
2017-06-05 added v0 gerber files
    [main_clock_board.brd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]
2017-06-07 added gound planes
    [main_clock_board.brd, main_clock_board.sch]
2017-06-07 DRC check ok
    [main_clock_board.brd]
2017-06-07 skilscreen correction
    [main_clock_board.brd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]
2017-06-08 fixed ds3231 package to SO16W
    [main_clock_board.brd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]
2017-06-08 fixing r4,r7
    [main_clock_board.brd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]
2017-06-09 added fin gerb files
    [main_clock_board.GBL, main_clock_board.GBO, main_clock_board.GBS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]

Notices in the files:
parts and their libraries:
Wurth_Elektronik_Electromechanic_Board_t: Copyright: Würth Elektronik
